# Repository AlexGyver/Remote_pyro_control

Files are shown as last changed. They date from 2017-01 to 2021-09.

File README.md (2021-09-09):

# 10 канальный пиропульт на Ардуино и модулях nRF24L01

## Папки

**Библиотеки** - библиотека для модуля связи и клавиатуры, установить в C:\Program Files\Arduino\libraries
  
**Без обратной связи** - пиропульт без обратной связи, для тех у кого не работает обратная
  
- **pyroRX** - скетч ПРИЁМНИКА (receiver)
- **pyroTX** - скетч ПЕРЕДАТЧИКА (transmitter)

**С обратной связью** - пиропульт со встроенным тестером аккумулятора и обратной связью с пультом
  
- **pyroRX** - скетч ПРИЁМНИКА (receiver)
- **pyroTX** - скетч ПЕРЕДАТЧИКА (transmitter)

## Схема подключения
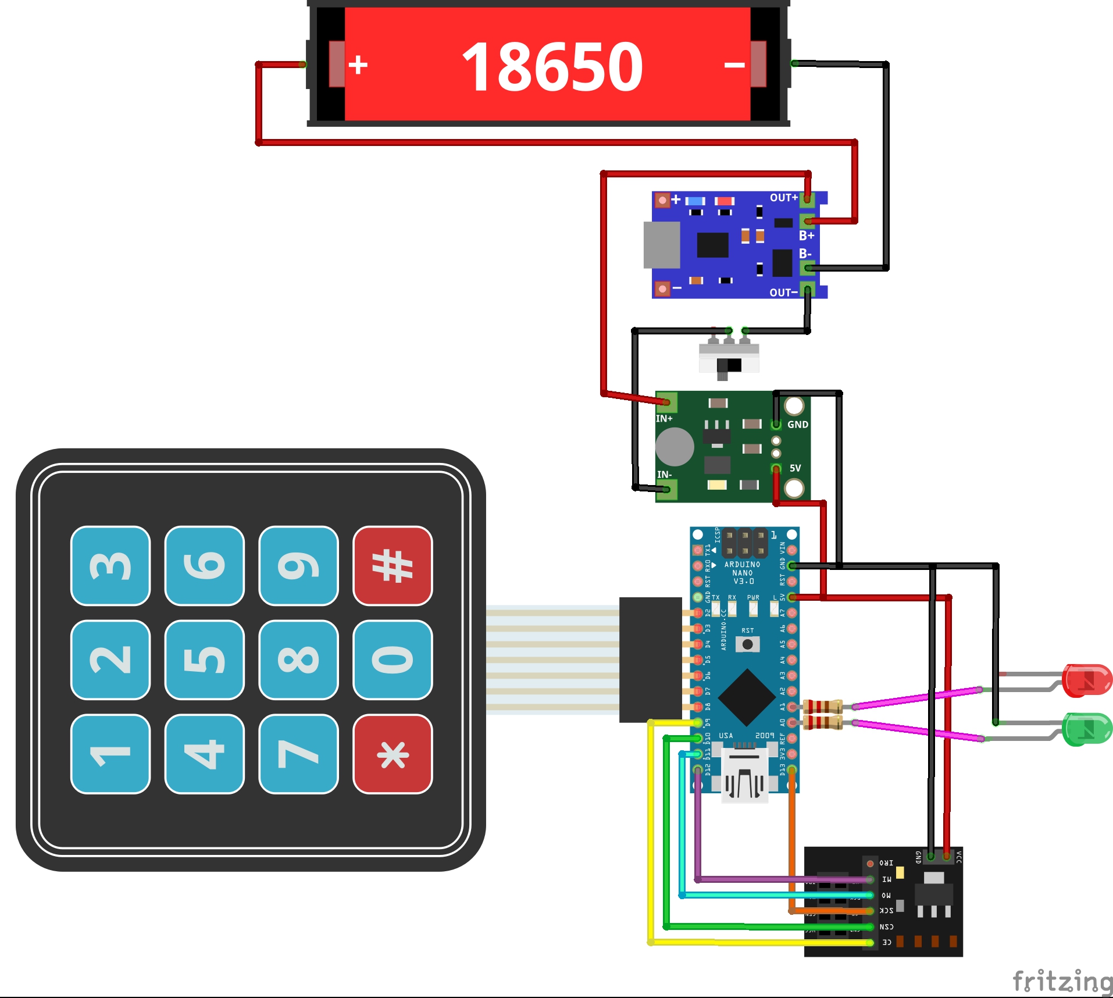
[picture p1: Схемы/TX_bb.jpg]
ПЕРЕДАТЧИК


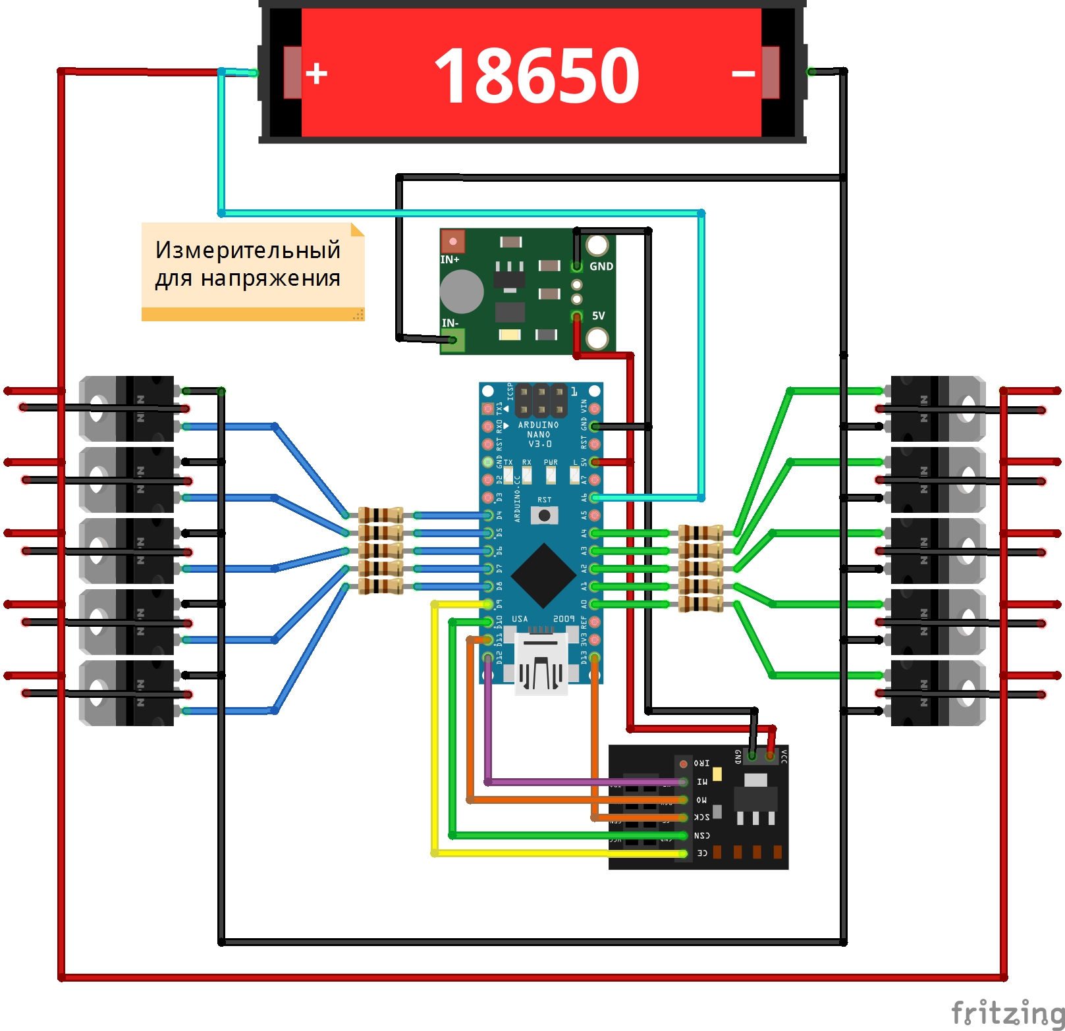
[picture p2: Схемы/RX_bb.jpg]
ПРИЁМНИК


## Видео по теме
Старая версия самодельного детонатора:

* ► https://youtu.be/CV0p9t0wjMk

Мои полезные видео про радио модуль nRF24L01

* ► https://youtu.be/ACVtKDJVXS4
* ► https://youtu.be/p0v2vSmajx8

##  Материалы и компоненты
Всё указанное ниже можно найти здесь
http://alexgyver.ru/arduino_shop/

* Arduino NANO 2 шт. https://ali.ski/2tl01

* Модуль связи мощный 2 шт. https://ali.ski/P5Fvs
* Или модуль связи мини 2 шт. https://ali.ski/-6IWjq
* Адаптер питания 2 шт. https://ali.ski/N9tWHu
* Или такой 2 шт. https://ali.ski/3BVQ8

* Акумы на выбор, 2шт. http://alexgyver.ru/18650/
* Холдер под 18650 2 шт. https://ali.ski/VkefzP
* Модуль повыш. до 5В 2 шт. https://ali.ski/jOArt
* Модуль защиты акума https://ali.ski/4JwuP

* Клавиатура 4х3 мембр. https://ali.ski/oF4VN
* Клавиатура 4х3 механ. https://ali.ski/wUPgai
* Светодиодов пачка https://ali.ski/lMksXV
* Резисторов пачка https://ali.ski/44Cvd
* Выключатели https://ali.ski/NXpUq3
* Корпус как на видео https://ali.ski/H_r63

* Макетки как на видео https://ali.ski/jw8pkU
* Мосфеты 10 шт. https://ali.ski/lI2mpi
* Резисторы 100 Ом https://ali.ski/3tq22
* Клеммник пружинный! https://ali.ski/6L-lB
* Провод из видео (1 мм) https://ali.ski/3VTwE
* Провод всех размеров, кусачки, припой, паяльники и куча всего для пайки http://alexgyver.ru/all-for-soldering/

## Вам также пригодится 
* Всё для пайки http://alexgyver.ru/all-for-soldering/
* Электронные компоненты http://alexgyver.ru/electronics/

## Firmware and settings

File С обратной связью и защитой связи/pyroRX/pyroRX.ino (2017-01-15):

/*   Данный скетч делает следующее: передатчик (TX) отправляет массив
     данных, который генерируется согласно показаниям с кнопки и с
     двух потенциомтеров. Приёмник (RX) получает массив, и записывает
     данные на реле, сервомашинку и генерирует ШИМ сигнал на транзистор.
    by AlexGyver 2016
*/

#include <SPI.h>
#include "nRF24L01.h"
#include "RF24.h"

float my_vcc_const = 1.1; // начальное значение константы должно быть 1.1

byte MOSFET[10] = {18, 4, 5, 6, 7, 8, 14, 15, 16, 17};  //массив пинов, к которым подключены мосфеты
boolean FLAGS[10]; // массив, хранящий время для таймера каждого мосфета? по умолчанию {0,0,0,0,0,0,0,0}
unsigned long TIMES[10]; // массив, хранящий состояния мосфетов
byte battery_pin = 6;    // сюда подключен аккумулятор для измерения напряжения
boolean RXstate;

byte receiv_data[2];

int fuse_time = 1500;  // время в миллисекундах, которое ток будет подаваться  на спираль
int battery_check = 2800; // нижняя граница заряда аккумулятора для защиты, в милливольтах!

byte crypt_key = 123;    // уникальный ключ для защиты связи
int check = 111;         // условный код, для обратной связи

RF24 radio(9, 10); // "создать" модуль на пинах 9 и 10 Для Уно
//RF24 radio(9,53); // для Меги

byte address[][6] = {"1Node", "2Node", "3Node", "4Node", "5Node", "6Node"}; //возможные номера труб

void setup() {
  Serial.begin(9600); //открываем порт для связи с ПК

  // настраиваем пины мосфетов как выходы по массиву
  for (int i = 0; i <= 9; i++) {
    pinMode(MOSFET[i], OUTPUT);
  }

  radio.begin(); //активировать модуль
  radio.setAutoAck(1);         //режим подтверждения приёма, 1 вкл 0 выкл
  radio.setRetries(0, 15);    //(время между попыткой достучаться, число попыток)
  radio.enableAckPayload();    //разрешить отсылку данных в ответ на входящий сигнал
  radio.setPayloadSize(32);     //размер пакета, в байтах

  radio.openReadingPipe(1, address[0]);     //хотим слушать трубу 0
  radio.setChannel(0x60);  //выбираем канал (в котором нет шумов!)

  radio.setPALevel (RF24_PA_MAX); //уровень мощности передатчика. На выбор RF24_PA_MIN, RF24_PA_LOW, RF24_PA_HIGH, RF24_PA_MAX
  radio.setDataRate (RF24_1MBPS); //скорость обмена. На выбор RF24_2MBPS, RF24_1MBPS, RF24_250KBPS
  //должна быть одинакова на приёмнике и передатчике!
  //при самой низкой скорости имеем самую высокую чувствительность и дальность!!

  radio.powerUp(); //начать работу
  radio.startListening();  //начинаем слушать эфир, мы приёмный модуль
}

void loop() {
  byte pipeNo;
  while ( radio.available(&pipeNo)) {             // слушаем эфир со всех труб
    radio.read( &receiv_data, sizeof(receiv_data) );      // читаем входящий сигнал

    if (receiv_data[0] == crypt_key) {

      if (receiv_data[1] == check) {
        int voltage = analogRead(battery_pin) * readVcc() / 1024;
        if (voltage > battery_check) RXstate = 1; else RXstate = 0;

        radio.writeAckPayload(pipeNo, &RXstate, sizeof(RXstate) );
        Serial.println("Check state sent");
      } else {
        if (FLAGS[receiv_data[1]] == 0) {
          FLAGS[receiv_data[1]] = 1;                           // поднять флаг для мосфета, по входящему сигналу
          TIMES[receiv_data[1]] = millis();                    // запомнить время прихода сигнала
          digitalWrite(MOSFET[receiv_data[1]], HIGH);          // подать питание на мосфет (на запал)

          Serial.print("Fuse #"); Serial.print(receiv_data[1]); Serial.println(" ON");
        }
      }
    }
  }

  for (int i = 0; i <= 9; i++) {                  // пройтись по всем 10ти мосфетам
    if (millis() - TIMES[i] > fuse_time && FLAGS[i] == 1) {  // если время с момента открытия мосфета > заданного
      FLAGS[i] = 0;                                                 // опустить флаг
      digitalWrite(MOSFET[i], LOW);                                 // закрыть мосфет, погасить запал
      Serial.print("Fuse #"); Serial.print(i); Serial.println(" OFF");
    }
  }
}

long readVcc() { //функция чтения внутреннего опорного напряжения, универсальная (для всех ардуин)
#if defined(__AVR_ATmega32U4__) || defined(__AVR_ATmega1280__) || defined(__AVR_ATmega2560__)
  ADMUX = _BV(REFS0) | _BV(MUX4) | _BV(MUX3) | _BV(MUX2) | _BV(MUX1);
#elif defined (__AVR_ATtiny24__) || defined(__AVR_ATtiny44__) || defined(__AVR_ATtiny84__)
  ADMUX = _BV(MUX5) | _BV(MUX0);
#elif defined (__AVR_ATtiny25__) || defined(__AVR_ATtiny45__) || defined(__AVR_ATtiny85__)
  ADMUX = _BV(MUX3) | _BV(MUX2);
#else
  ADMUX = _BV(REFS0) | _BV(MUX3) | _BV(MUX2) | _BV(MUX1);
#endif
  delay(2); // Wait for Vref to settle
  ADCSRA |= _BV(ADSC); // Start conversion
  while (bit_is_set(ADCSRA, ADSC)); // measuring
  uint8_t low  = ADCL; // must read ADCL first - it then locks ADCH
  uint8_t high = ADCH; // unlocks both
  long result = (high << 8) | low;

  result = my_vcc_const * 1023 * 1000 / result; // расчёт реального VCC
  return result; // возвращает VCC
}

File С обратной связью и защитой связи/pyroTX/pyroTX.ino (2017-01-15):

/*
  Created 2017
  by AlexGyver
  AlexGyver Home Labs Inc.
*/
#include "Keypad.h"       //библиотека клавиатуры
#include <SPI.h>          // библиотека для работы с шиной SPI
#include "nRF24L01.h"     // библиотека радиомодуля
#include "RF24.h"         // ещё библиотека радиомодуля

RF24 radio(9, 10); // "создать" модуль на пинах 9 и 10 Для Уно
byte address[][6] = {"1Node", "2Node", "3Node", "4Node", "5Node", "6Node"}; //возможные номера труб

byte redLED = 14;
byte greenLED = 15;

byte crypt_key = 123;    // уникальный ключ для защиты связи
int check = 111;         // условный код, для обратной связи
byte transm_data[2];     // массив отправляемых данных (уникальный ключ + код кнопки)
boolean check_answer;

const byte ROWS = 4; //4 строки у клавиатуры
const byte COLS = 3; //три столбца
char keys[4][3] = {
  {'1', '2', '3'},
  {'4', '5', '6'},
  {'7', '8', '9'},
  {'*', '0', '#'}
};
byte rowPins[ROWS] = {8, 7, 6, 5}; //Подключены строки (4 пина)
byte colPins[COLS] = {4, 3, 2}; //подключены столбцы (3 пина)
Keypad keypad = Keypad( makeKeymap(keys), rowPins, colPins, ROWS, COLS ); //создать клавиатуру
boolean flag;

void setup() {
  Serial.begin(9600);

  transm_data[0] = crypt_key;      // задать уникальный ключ для защиты связи

  pinMode(redLED, OUTPUT);
  pinMode(greenLED, OUTPUT);
  digitalWrite(greenLED, HIGH);    // зажечь зелёный светодиод

  radio.begin(); //активировать модуль
  radio.setAutoAck(1);         //режим подтверждения приёма, 1 вкл 0 выкл
  radio.setRetries(0, 15);    //(время между попыткой достучаться, число попыток)
  radio.enableAckPayload();    //разрешить отсылку данных в ответ на входящий сигнал
  radio.setPayloadSize(32);     //размер пакета, в байтах

  radio.openWritingPipe(address[0]);   //мы - труба 0, открываем канал для передачи данных
  radio.setChannel(0x60);  //выбираем канал (в котором нет шумов!)

  radio.setPALevel (RF24_PA_MAX); //уровень мощности передатчика. На выбор RF24_PA_MIN, RF24_PA_LOW, RF24_PA_HIGH, RF24_PA_MAX
  radio.setDataRate (RF24_1MBPS); //скорость обмена. На выбор RF24_2MBPS, RF24_1MBPS, RF24_250KBPS
  //должна быть одинакова на приёмнике и передатчике!
  //при самой низкой скорости имеем самую высокую чувствительность и дальность!!

  radio.powerUp(); //начать работу
  radio.stopListening();  //не слушаем радиоэфир, мы передатчик
}

void loop() {
  byte gotByte;
  char key = keypad.waitForKey();      // ожидать ввод с клавиатуры, принять символ
  int keyInt = key - '0';              // перевести символ в целочисленный тип

  if (keyInt >= 0 && keyInt <= 9 && flag == 1) {  // если число от 0 до 9 и флаг поднят
    digitalWrite(greenLED, HIGH);                         // включить зелёный светодиод
    digitalWrite(redLED, LOW);                            // погасить красный светодиод
    transm_data[1] = keyInt;                              // на второе место массива ставим нажатую кнопку
    radio.write(&transm_data, sizeof(transm_data));       // отправить массив по радио
    delay(10);
    digitalWrite(greenLED, LOW);                          // погасить зелёный светодиод
    digitalWrite(redLED, HIGH);                           // зажечь красный светодиод

  } else if (key == '*') {                                // если символ *
    flag = 0;                                             // опустить флаг

    digitalWrite(redLED, LOW);                            // погасить красный светодиод
    digitalWrite(greenLED, LOW);                          // погасить зелёный светодиод
    delay(100);                                           // задержка для эпичности

    transm_data[1] = check;                               // на второе место массива ставим условный код для проверки
    if ( radio.write(&transm_data, sizeof(transm_data)) ) {  // отправляем 
      if (!radio.available()) {                           // если не получаем ответ
        Serial.println("No answer");
        digitalWrite(greenLED, HIGH);                     // включить зелёный светодиод
      } else {
        while (radio.available() ) {                      // если в ответе что-то есть
          radio.read( &check_answer, 1);                  // читаем
          if (check_answer == 1) {                        // если статус = 1 (готов к работе)
            flag = 1;                                     // поднять флаг готовности к работе
            digitalWrite(redLED, HIGH);                   // зажечь красный светодиод
            Serial.println("Status OK");
          } else {                                        // если статус = 0 (акум разряжен)
            Serial.println("Status BAD");
            for (int i = 0; i < 5; i++) {                 // моргнуть 6 раз зелёным светодиодом
              digitalWrite(greenLED, HIGH);
              delay(200);
              digitalWrite(greenLED, LOW);
              delay(100);
            }
            digitalWrite(greenLED, HIGH);                 // включить зелёный светодиод при ошибке
          }
        }
      }
    } else {
      Serial.println("Sending failed");              // ошибка отправки
      digitalWrite(greenLED, HIGH);                  // включить зелёный светодиод
    }

  } else if (key == '#') {                        // если символ №
    flag = 0;                                     // опустить флаг
    digitalWrite(greenLED, HIGH);                 // зажечь зелёный светодиод
    digitalWrite(redLED, LOW);                    // погасить красный светодиод
  }
}

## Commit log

2017-01-14 Добавлены прошивки
2017-01-15 Обновил скетчи
2017-01-15 новые добавки
2017-01-15 Добавлены схемы
    [RX.fzz, TX.fzz]
2017-01-15 Обновил ридми
2017-01-15 схемы
2017-01-15 Добавил скетч с защитой связи по уникальному ключу
2017-02-13 Обновлено
